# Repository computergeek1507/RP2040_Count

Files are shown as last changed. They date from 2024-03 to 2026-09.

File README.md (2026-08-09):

# Copyright and Disclaimer
Copyright: Scott Hanson

This documentation describes Open Hardware and is licensed under the CERN Open Hardware License Version 2 - Strongly Reciprocal. (CERN-OHL-S)

You may redistribute and modify this documentation under the terms of the CERN OHL-S-v2 (https://ohwr.org/cern_ohl_s_v2.txt). This documentation is distributed WITHOUT ANY EXPRESS OR IMPLIED WARRANTY, INCLUDING OF MERCHANTABILITY, SATISFACTORY QUALITY AND FITNESS FOR A PARTICULAR PURPOSE. Please see the CERN OHL v2-S for applicable conditions

**Under CERN OHL-S-v2, derivative work must be publicly released as defined in subsection 3.3**

# SB Pixel Count




SB Pixel Count is a 'pocket' Pixel Counter. The original (V1) board uses a Waveshare RP2040-Tiny Development Board.  All the design files are open source and available on github.

To order PCBs upload the ["GERBER-SB_Pixel_Count.zip"](https://github.com/computergeek1507/SB_Pixel_Count/raw/main/V1/PCB/jlcpcb/production_files/GERBER-SB_Pixel_Count.zip) file in the "V1\PCB\jlcpcb\production_files" folder to jlcpcb.com. Use the "BOM-SB_Pixel_Count.csv" for the JLC Assembly BOM and "CPL-SB_Pixel_Count.csv" as the footprint placement file.

## Assembly

The raw PCB's from JLC will be missing the RP2040-Tiny, OLED, Push Button and PigTails. These parts need to be soldered manually. The case is designed for flat pigtails.

Print the case out of PETG with 0.1mm layer height. Use #2-56 3/8" machine screws for case.

## Board Variants

This repo tracks a few PCB/firmware revisions side by side. `Firmware/SB_Pixel_Count/BoardConfig.h` selects the pin mapping for each via a build flag (`VERSION1`/`VERSION2`/`VERSION3`); the default is `VERSION2`.

| Variant | Folder | MCU module | Firmware | Interactive BOM | Notes |
| --- | --- | --- | --- | --- | --- |
| V1 (Original) | [`V1/`](https://github.com/computergeek1507/SB_Pixel_Count/tree/main/V1) | Waveshare RP2040-Tiny | `VERSION1` | [Open](https://computergeek1507.github.io/SB_Pixel_Count/V1/PCB/bom/ibom.html) | The board described above. |
| V2 | [`V2/`](https://github.com/computergeek1507/SB_Pixel_Count/tree/main/V2) | Seeed XIAO RP2040 | `VERSION2` (default) | [Open](https://computergeek1507.github.io/SB_Pixel_Count/V2/PCB/bom/ibom.html) | Standard redesign around the XIAO RP2040 module - firmware updates over USB (drag-and-drop UF2), no external programmer needed. |
| V2 Lite | [`V2 Lite/`](https://github.com/computergeek1507/SB_Pixel_Count/tree/main/V2%20Lite) | ATtiny1614 (megaTinyCore) | [`Firmware/ATtiny1614_Count/`](https://github.com/computergeek1507/SB_Pixel_Count/tree/main/Firmware/ATtiny1614_Count) | [Open](https://computergeek1507.github.io/SB_Pixel_Count/V2%20Lite/PCB/bom/ibom.html) | Cost-reduced BOM built around a bare ATtiny1614 instead of a RP2040 module; trades USB firmware updates for a UPDI programmer requirement. Uses FAB_LED/SSD1306Ascii instead of the Adafruit libraries to fit in 16KB flash / 2KB RAM. Shares the same case as V2 (`V2/Case/` and `V2 Lite/Case/` are the same design). |
| V3 Pro | [`V3 Pro/`](https://github.com/computergeek1507/SB_Pixel_Count/tree/main/V3%20Pro) | Seeed XIAO RP2040 | `VERSION3` | [Open](https://computergeek1507.github.io/SB_Pixel_Count/V3%20Pro/PCB/bom/ibom.html) | Adds a second button and a microSD card slot for playing back xLights FSEQ sequences on the strip (`Firmware/SB_Pixel_Count/FseqPlayer.*`). |

Each variant folder that has its own `PCB/` directory also has its own `jlcpcb/production_files` gerbers/BOM/CPL for ordering that specific board.

## [Video of SB Pixel Count](https://youtu.be/7ThN9TBFA-g)

## [Part BOM](https://github.com/computergeek1507/SB_Pixel_Count/raw/main/V1/PCB/SB_Pixel_Count_BOM.ods)

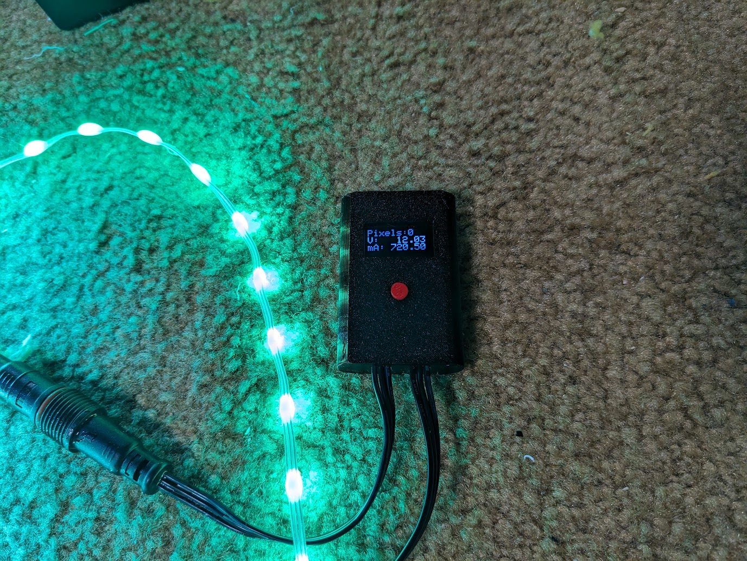
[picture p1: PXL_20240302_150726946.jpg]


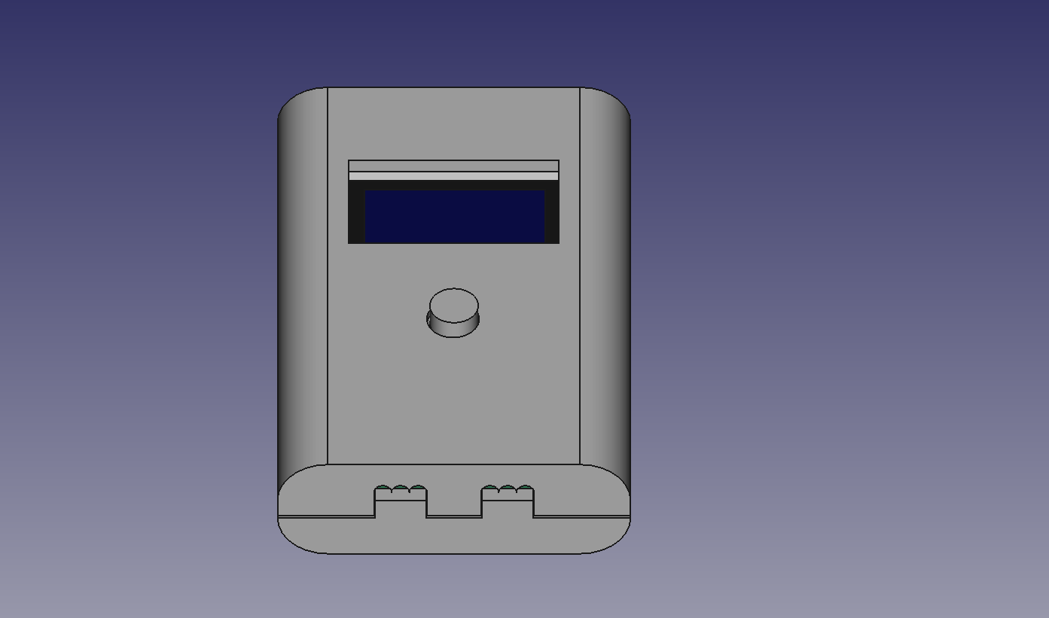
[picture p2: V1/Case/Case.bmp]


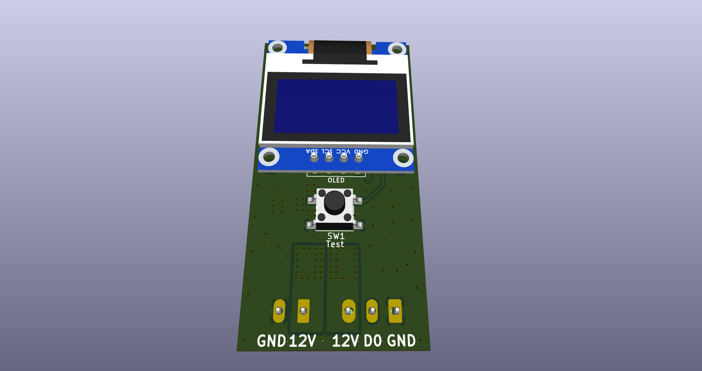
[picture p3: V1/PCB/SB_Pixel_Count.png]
Image of SB Pixel Count


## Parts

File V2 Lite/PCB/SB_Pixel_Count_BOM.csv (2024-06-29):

Reference | Value | Datasheet | Qty | Digi-Key_PN | MPN
C1,C5,C6 | 0.1uF | ~ | 3 | 1276-1005-1-ND | CL10B104KO8NNNC
C3,C4 | 10uF | ~ | 2 | 490-5523-1-ND | GRM21BR61E106KA73L
J2 | String1 | ~ | 1 | 277-5737-ND/ED10555-ND | 1843619/OSTTJ0311530
J3 | OLED | https://www.amazon.com/dp/B06XRBTBTB/ref=sspa_dk_detail_0 | 1
R1 | 33ohm | ~ | 1 | 311-33GRCT-ND | RC0603JR-0733RL
R2 | 0.1 OHM 2W | ~ | 1 | CSRN2512FTR100CT-ND | CSRN2512FTR100
R3,R4 | 10K | ~ | 2 | 311-10.0KHRCT-ND | RC0603FR-0710KL
SW1 | Test | ~ | 1 | CKN10880CT-ND | PTS645SL43SMTR92 LFS
TB1 | Power In |  | 1 | A98472-ND | 4DB-P108-02
U1 | 74AHCT1G125 | http://www.ti.com/lit/sg/scyt129e/scyt129e.pdf | 1 | 74AHCT1G125W5-7DICT-ND | 74AHCT1G125W5-7
U2 | MOUDLE-SEEEDUINO-XIAO |  | 1 | 1597-102010428-ND | 102010428
U3 | AMS1117-5.0 | http://www.advanced-monolithic.com/pdf/ds1117.pdf | 1 | 488-LM1117MPX-50NOPBCT-ND | LM1117MPX-50NOPB
U4 | INA219BxD | http://www.ti.com/lit/ds/symlink/ina219.pdf | 1 | 296-27899-1-ND | INA219BIDR

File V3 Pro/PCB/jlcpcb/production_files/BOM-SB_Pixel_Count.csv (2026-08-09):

Comment | Designator | Footprint | LCSC | Quantity
0.1 OHM 2W | R2 | R_2512_6332Metric_Pad1.40x3.35mm_HandSolder | C2903476 | 1
0.1uF | C1,C5,C6 | C_0603_1608Metric_Pad1.08x0.95mm_HandSolder | C14663 | 3
10K | R3,R4 | R_0603_1608Metric_Pad0.98x0.95mm_HandSolder | C25804 | 2
10uF | C3,C4 | C_0805_2012Metric_Pad1.18x1.45mm_HandSolder | C15850 | 2
33ohm | R1 | R_0603_1608Metric_Pad0.98x0.95mm_HandSolder | C23140 | 1
74AHCT1G125 | U1 | TSOP-5_1.65x3.05mm_P0.95mm | C7484 | 1
AMS1117-5.0 | U3 | SOT-223-3_TabPin2 | C6187 | 1
INA219BxD | U4 | SOIC-8_3.9x4.9mm_P1.27mm | C138706 | 1
Menu | SW2 | SW_PUSH_6mm | C2834918 | 1
TF-123-ARP9H17 | U5 | TF-SMD_TF-123-ARP9H15 | C2982548 | 1
Test | SW1 | SW_PUSH_6mm | C2834918 | 1

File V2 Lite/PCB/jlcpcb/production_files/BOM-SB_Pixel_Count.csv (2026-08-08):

Comment | Designator | Footprint | LCSC | Quantity
0.1 OHM 2W | R2 | R_2512_6332Metric_Pad1.40x3.35mm_HandSolder | C2903476 | 1
0.1uF | C1,C5,C6 | C_0603_1608Metric_Pad1.08x0.95mm_HandSolder | C14663 | 3
10K | R3,R4 | R_0603_1608Metric_Pad0.98x0.95mm_HandSolder | C25804 | 2
10uF | C2,C3,C4 | C_0805_2012Metric_Pad1.18x1.45mm_HandSolder | C15850 | 3
330 | R5 | R_0603_1608Metric_Pad0.98x0.95mm_HandSolder | C23138 | 1
33ohm | R1 | R_0603_1608Metric_Pad0.98x0.95mm_HandSolder | C23140 | 1
3v3 | D1 | LED_0603_1608Metric | C2286 | 1
74AHCT1G125 | U1 | TSOP-5_1.65x3.05mm_P0.95mm | C7484 | 1
AMS1117-5.0 | U3 | SOT-223-3_TabPin2 | C6187 | 1
AP2112K-3.3 | U2 | SOT-23-5 | C51118 | 1
ATtiny1614-SS | U6 | SOIC-14_3.9x8.7mm_P1.27mm | C481364 | 1
INA219BxD | U4 | SOIC-8_3.9x4.9mm_P1.27mm | C138706 | 1
Test | SW1 | SW_PUSH_6mm | C2834918 | 1

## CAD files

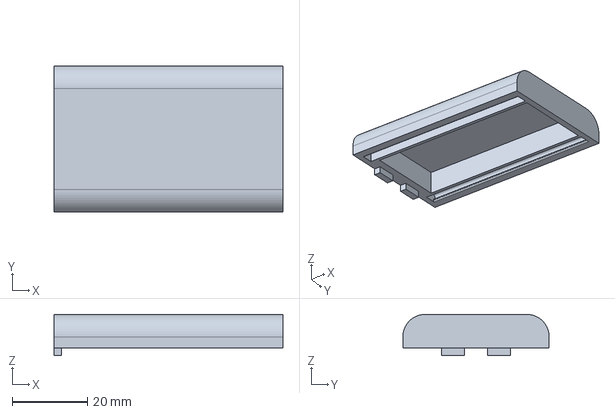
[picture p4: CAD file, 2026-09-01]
V2/Case/sb_pixel_count_caseV2_Snap.FCStd
61.0 x 39.0 x 11.0 mm

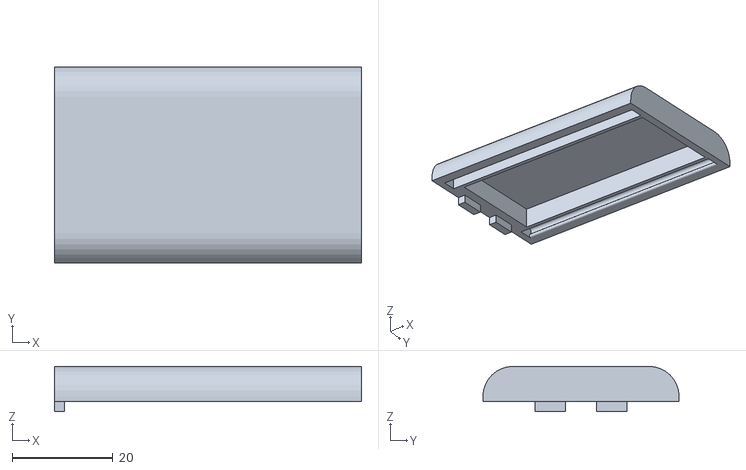
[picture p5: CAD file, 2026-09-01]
V2/Case/sb_pixel_count_caseV2_Snap-back_case.stl
61.0 x 39.0 x 9.00

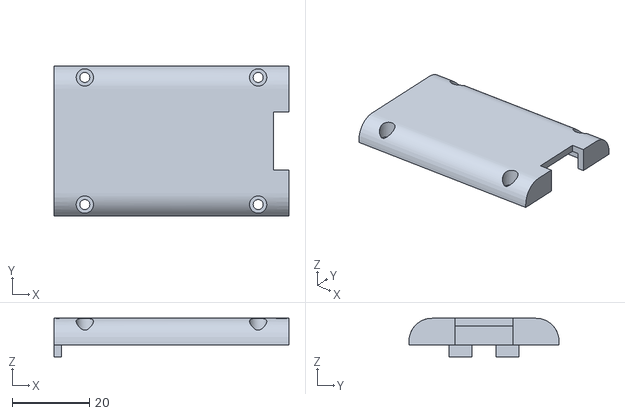
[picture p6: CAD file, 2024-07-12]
V2/Case/sb_pixel_count_caseV2-back_case_debug.stl
61.0 x 39.0 x 10.0

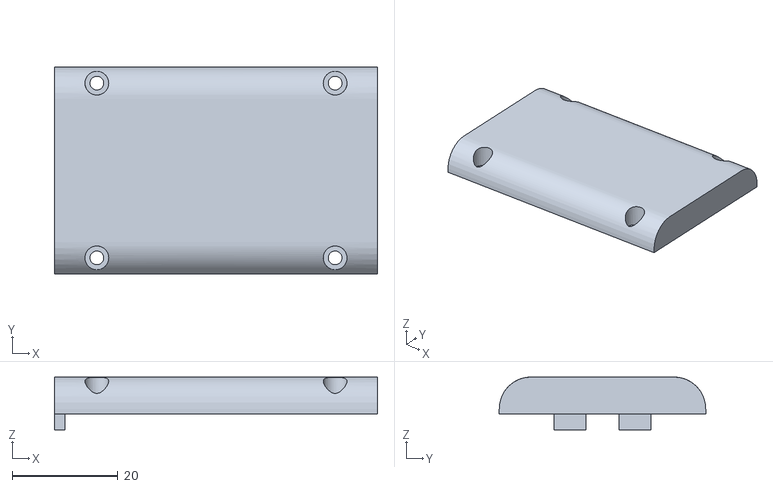
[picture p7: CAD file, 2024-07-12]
V2/Case/sb_pixel_count_caseV2-back_case.stl
61.0 x 39.0 x 10.0

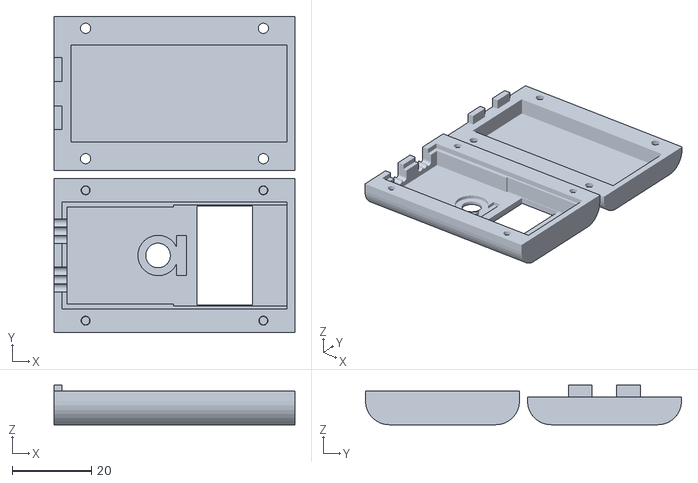
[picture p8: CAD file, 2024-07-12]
V2/Case/sb_pixel_count_caseV2-case.stl
61.0 x 80.0 x 10.0

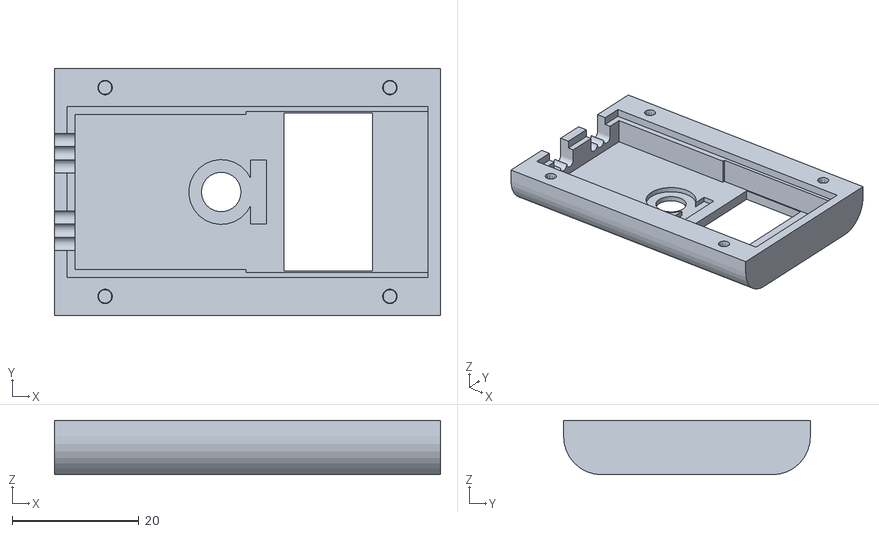
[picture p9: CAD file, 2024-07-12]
V2/Case/sb_pixel_count_caseV2-front_case.stl
61.0 x 39.0 x 8.60

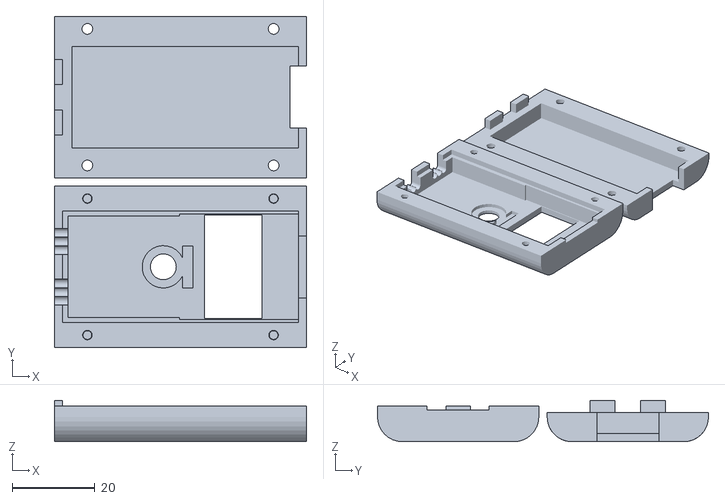
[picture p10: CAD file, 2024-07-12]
V2/Case/sb_pixel_count_caseV2-case_debug.stl
61.0 x 80.0 x 10.0

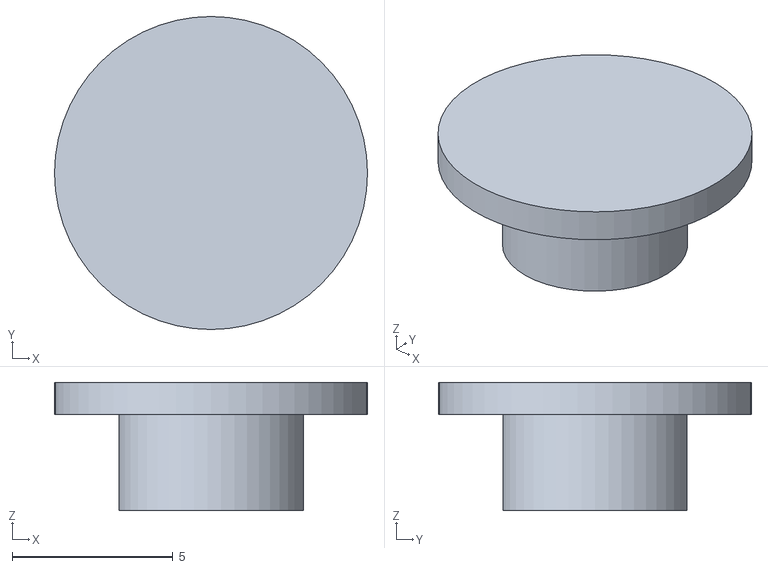
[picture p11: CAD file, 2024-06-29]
V2/Case/sb_pixel_count_caseV2-button.stl
9.75 x 9.75 x 4.00

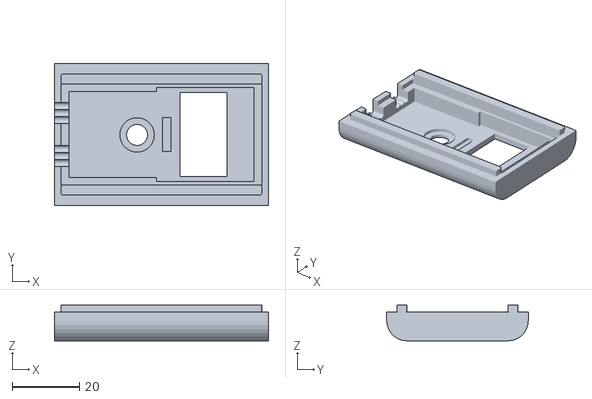
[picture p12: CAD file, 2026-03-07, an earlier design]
V1/Case/sb_pixel_count_case_snap-front_case.stl
63.5 x 42.0 x 10.6

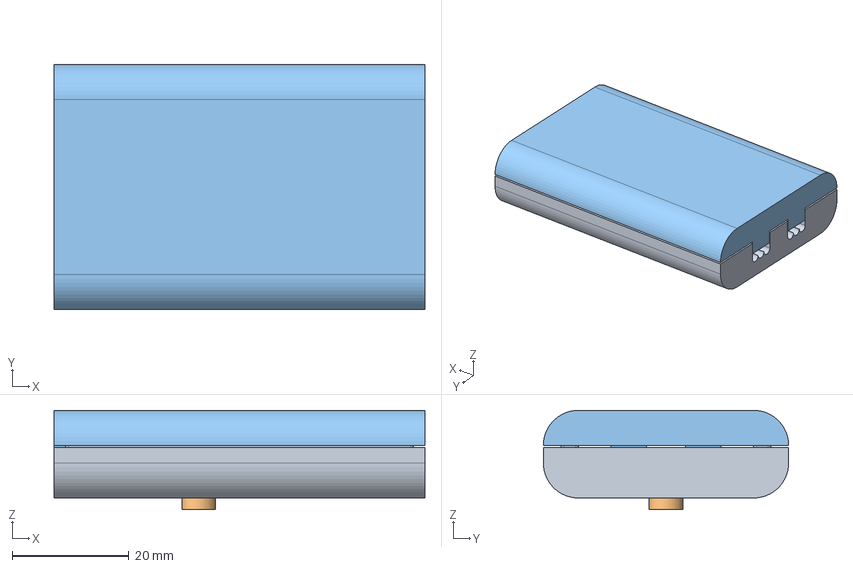
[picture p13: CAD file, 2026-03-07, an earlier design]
V1/Case/sb_pixel_count_case_snap.FCStd
63.5 x 42.0 x 17.0 mm
front_case
button
back_case

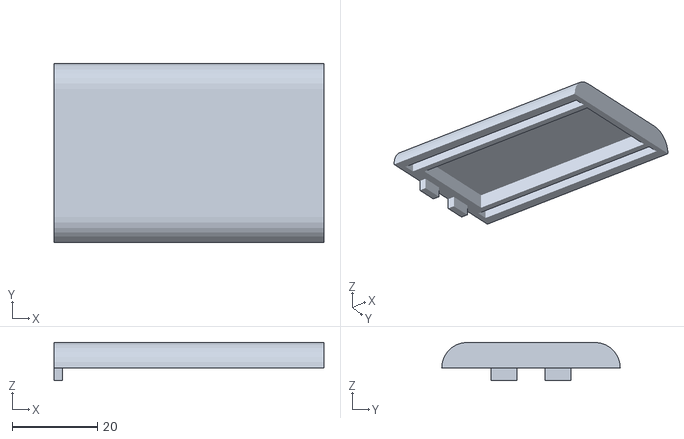
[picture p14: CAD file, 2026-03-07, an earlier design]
V1/Case/sb_pixel_count_case_snap-back_case.stl
63.5 x 42.0 x 9.00

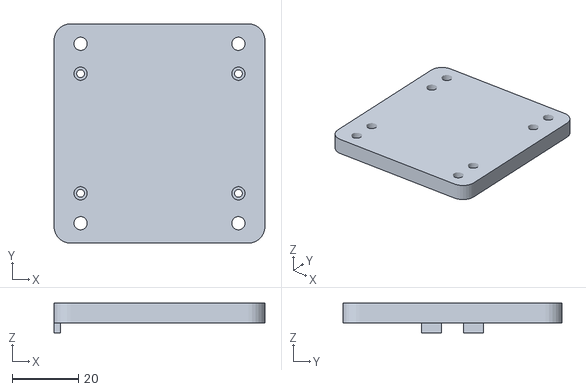
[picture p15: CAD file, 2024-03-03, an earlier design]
V1/Case/sb_pixel_count_case-back_case_wall.stl
63.5 x 66.0 x 9.00

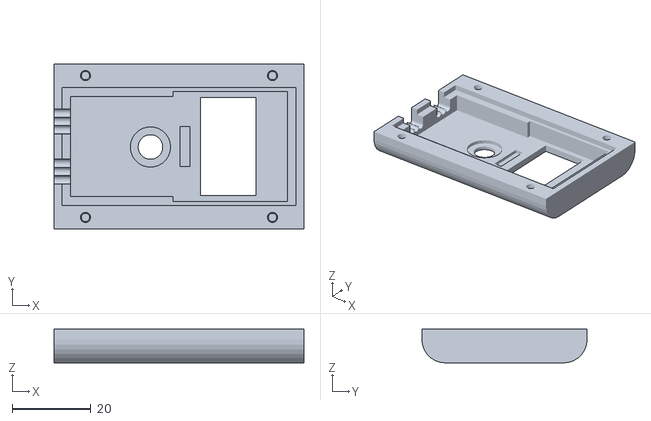
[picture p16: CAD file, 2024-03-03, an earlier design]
V1/Case/sb_pixel_count_case-front_case.stl
63.5 x 42.0 x 8.60

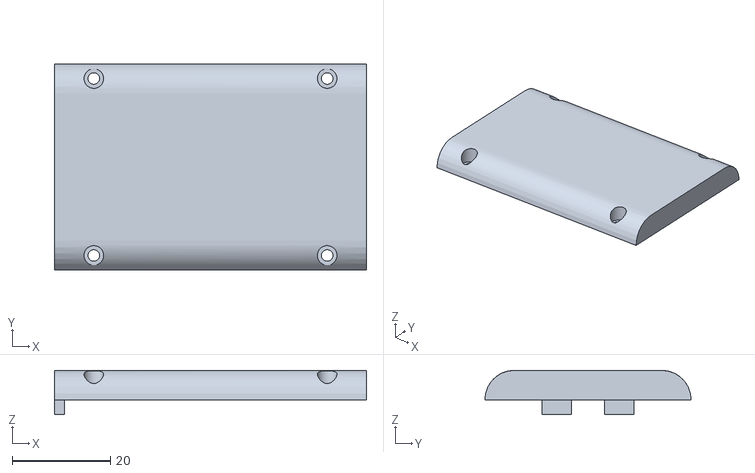
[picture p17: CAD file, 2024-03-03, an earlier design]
V1/Case/sb_pixel_count_case-back_case.stl
63.5 x 42.0 x 9.00

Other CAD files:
V2/Case/sb_pixel_count_caseV2.FCStd
V1/Case/sb_pixel_count_case-Button.stl
V1/Case/sb_pixel_count_case.FCStd

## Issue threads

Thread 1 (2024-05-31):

Programming RP2040

brymitch56, 2024-05-31:
Probably just my ignorance of the RP2040, but what is the recommended method for programming the board for this application? I see the .ino file, but I'm getting errors using the Arduino IDE. The compiler is saying it found multiple libraries for all of the included libraries, although I've confirmed only one instance of each library is installed.

computergeek1507, 2024-05-31:
I also included the uf2 files as well, if you plugged in the rp2040 it should mount as a USB drive and you drag and drop the uf2 file into the USB drive.

brymitch56, 2024-05-31:
I saw that file, but didn't know what it was. Thanks. I'll give that a try. Might be helpful to put that information in the readme for others who may not be as familiar with the RP2040 like me.

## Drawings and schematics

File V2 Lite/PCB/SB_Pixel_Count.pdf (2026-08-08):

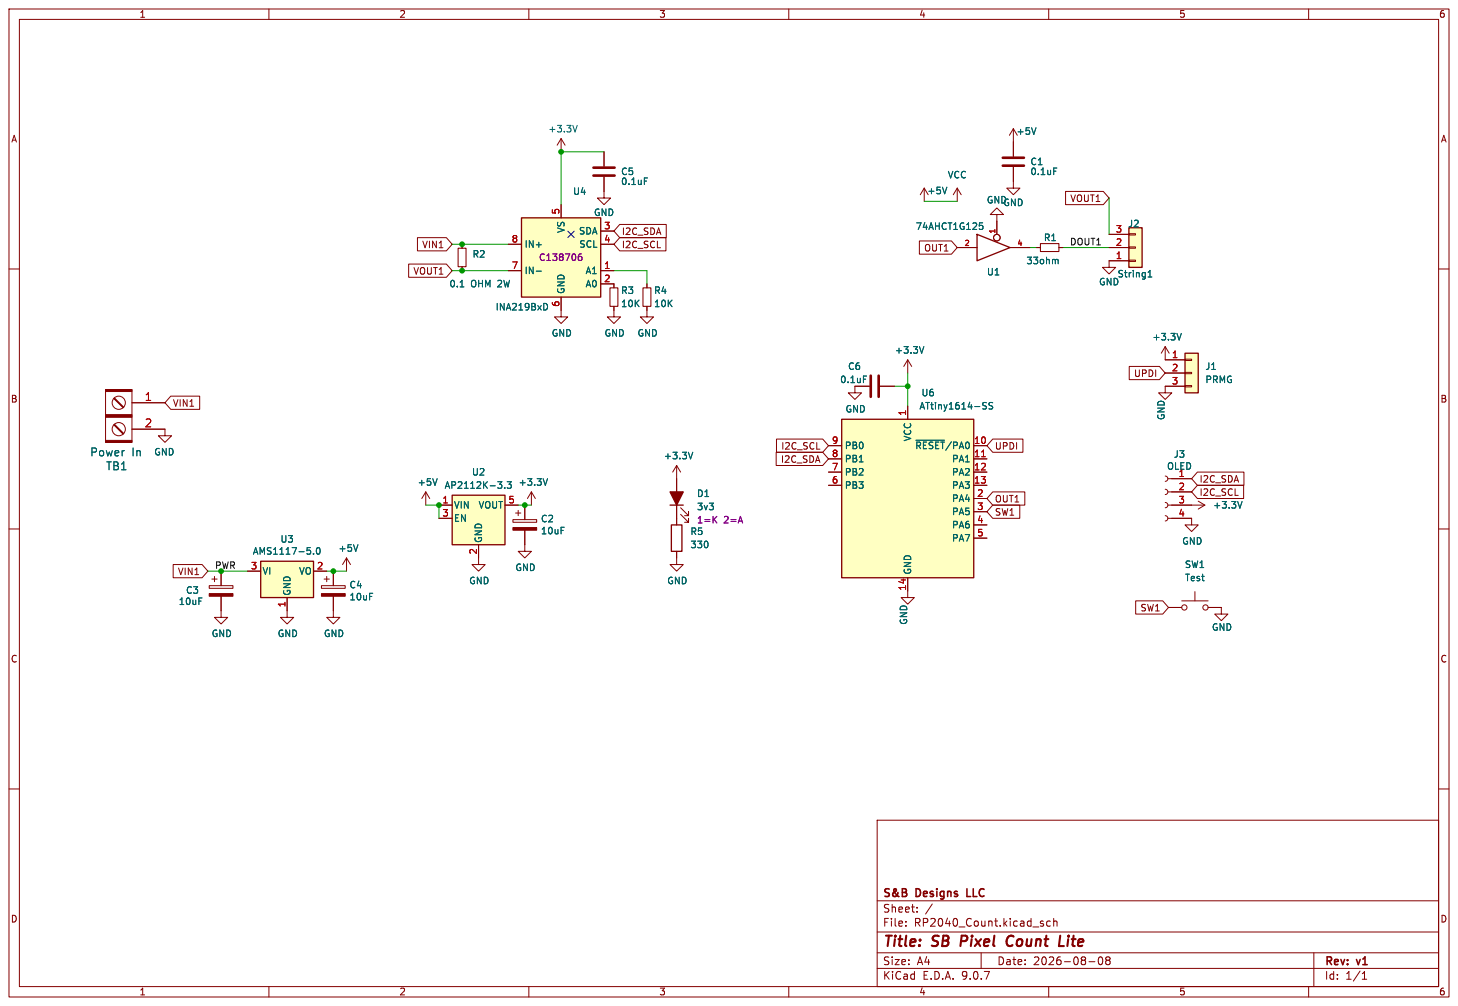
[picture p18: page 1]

Id: 1/1 Title: SB Pixel Count Lite

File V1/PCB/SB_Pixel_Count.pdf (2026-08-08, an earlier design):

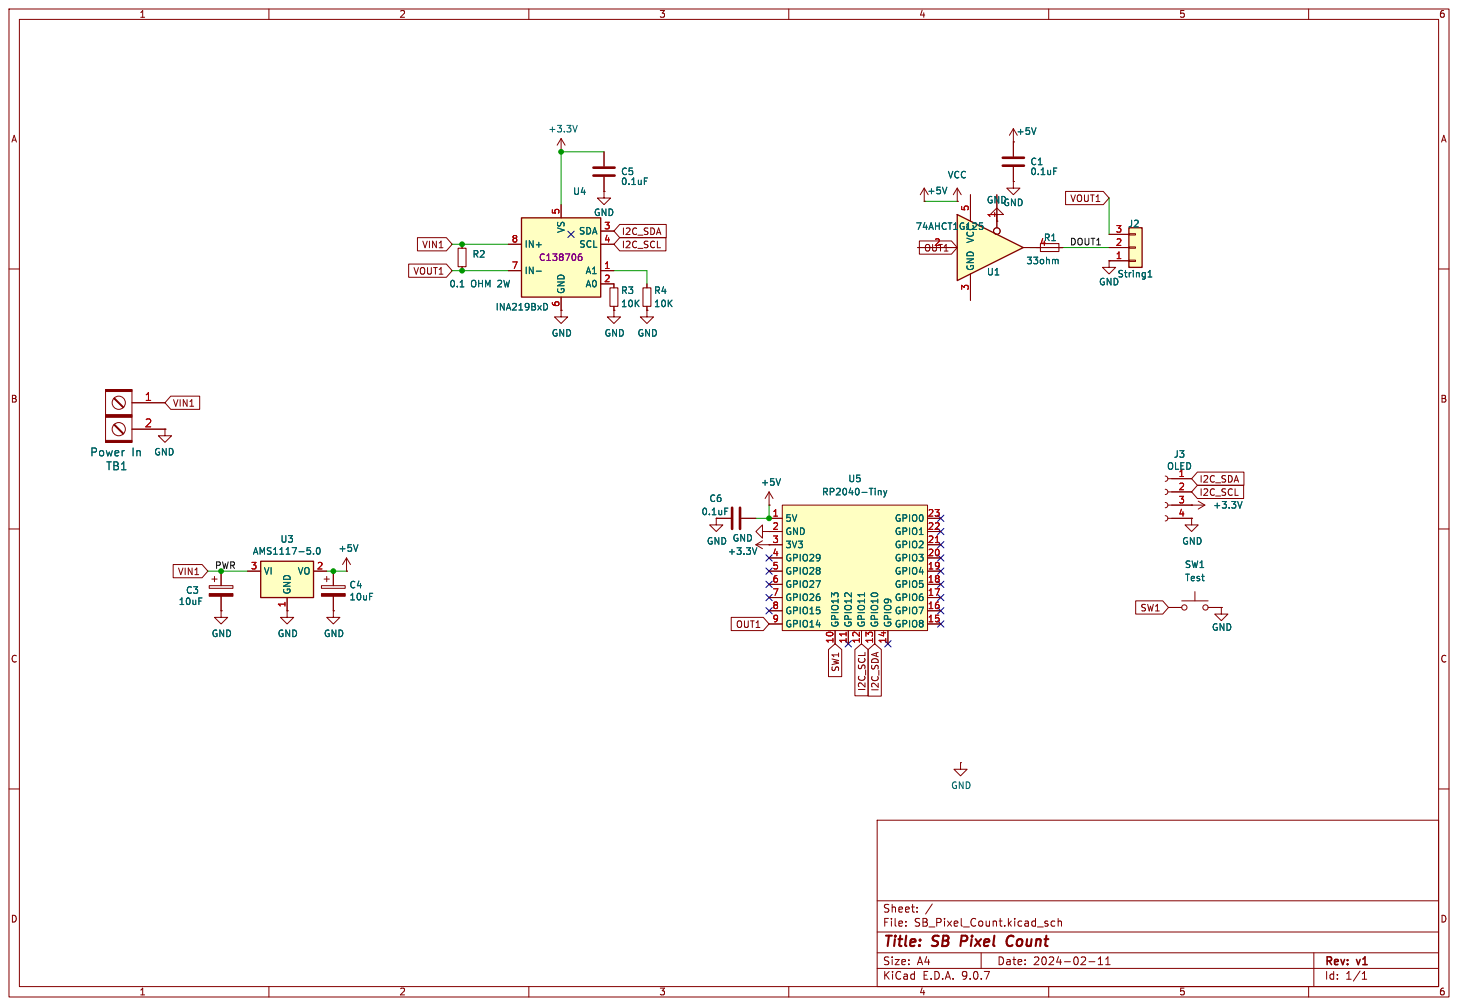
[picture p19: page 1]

6 SDA 3 SCL 4 A1 1 A0 2 GND GND GND

Id: 1/1 Title: SB Pixel Count File: SB_Pixel_Count.kicad_sch Sheet: /

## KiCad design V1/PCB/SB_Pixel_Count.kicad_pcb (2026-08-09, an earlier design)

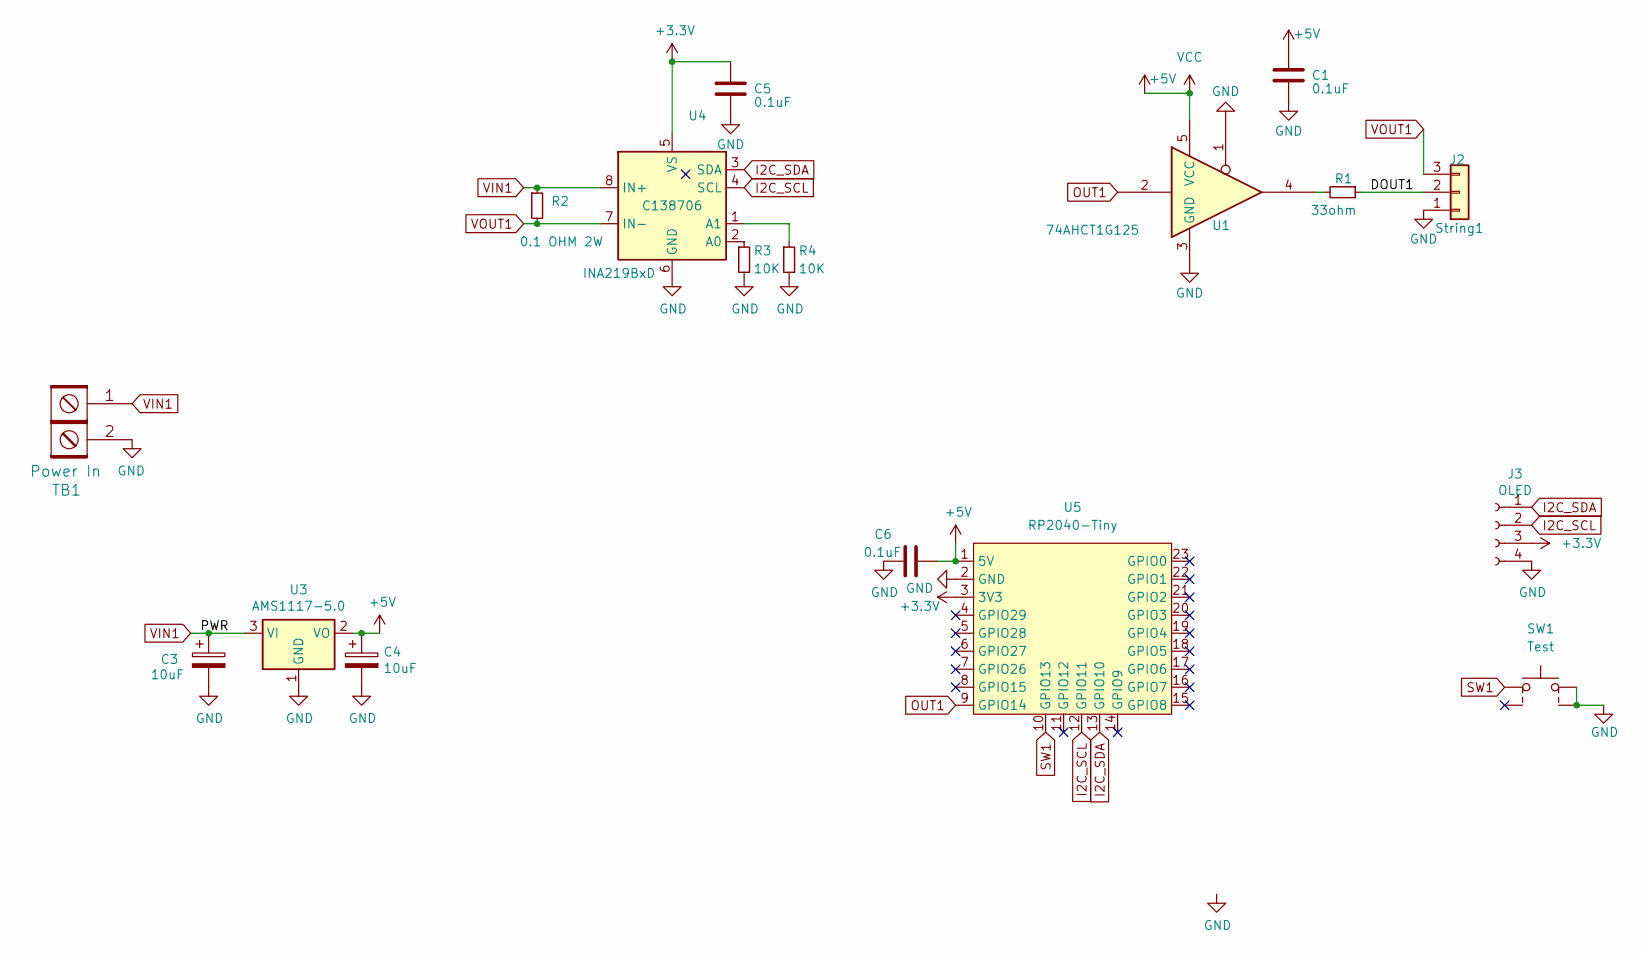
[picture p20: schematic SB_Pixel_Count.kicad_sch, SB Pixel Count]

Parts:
C1, C5: 0.1uF; C_0603_1608Metric_Pad1.08x0.95mm_HandSolder; MPN CL10B104KO8NNNC; LCSC C14663
C3, C4: 10uF; C_0805_2012Metric_Pad1.18x1.45mm_HandSolder; MPN GRM21BR61E106KA73L; Digi-Key_PN 490-5523-1-ND
C6: 0.1uF; C_0603_1608Metric_Pad1.08x0.95mm_HandSolder; MPN CL10B104KO8NNNC; Digi-Key_PN 1276-1005-1-ND
J2: String1; PhoenixContact_MCV_3.81mm_3.5mm_1x03_Vertical; MPN 1843619/OSTTJ0311530; Digi-Key_PN 277-5737-ND/ED10555-ND
J3: OLED; OLED-SSD1306-128X64-I2C-THT_SCOTT2; LCSC C225501
R1: 33ohm; R_0603_1608Metric_Pad0.98x0.95mm_HandSolder; MPN RC0603JR-0733RL; LCSC_PN C23140
R2: 0.1 OHM 2W; R_2512_6332Metric_Pad1.40x3.35mm_HandSolder; MPN CSRN2512FTR100; Digi-Key_PN CSRN2512FTR100CT-ND
R3, R4: 10K; R_0603_1608Metric_Pad0.98x0.95mm_HandSolder; MPN RC0603FR-0710KL; Digi-Key_PN 311-10.0KHRCT-ND
SW1: Test; SW_Push_1P1T_NO_6x6mm_H9.5mm; MPN PTS645SL43SMTR92 LFS; LCSC C2834918
TB1: Power In; PhoenixContact_MCV_1,5_2-G-3.81_1x02_P3.81mm_Vertical; MPN 4DB-P108-02; Digi-Key_PN A98472-ND
U1: 74AHCT1G125; TSOP-5_1.65x3.05mm_P0.95mm; MPN 74AHCT1G125W5-7; Digi-Key_PN 74AHCT1G125W5-7DICT-ND
U3: AMS1117-5.0; SOT-223-3_TabPin2; MPN LM1117MPX-50NOPB; LCSC_PN C6187
U4: INA219BxD; SOIC-8_3.9x4.9mm_P1.27mm; MPN INA219BIDR; LCSC C138706
U5: RP2040-Tiny; RP2040-Tiny_Scott

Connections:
+3.3V: C5.1, J3.3, U4.5 (VS), U5.3 (3V3)
+5V: C1.1, C4.1, C6.2, U1.5 (VCC), U3.2 (VO), U5.1 (5V)
/DOUT1: J2.2, R1.1
GND: C1.2, C3.2, C4.2, C5.2, C6.1, J2.1, J3.4, R3.2, R4.2, SW1.2, SW1.4, TB1.2, U1.1, U1.3 (GND), U3.1 (GND), U4.6 (GND), U5.2 (GND)
I2C_SCL: J3.2, U4.4 (SCL), U5.12 (GPIO11)
I2C_SDA: J3.1, U4.3 (SDA), U5.13 (GPIO10)
unnamed: R1.2, U1.4
unnamed: R3.1, U4.2 (A0)
unnamed: R4.1, U4.1 (A1)
OUT1: U1.2, U5.9 (GPIO14)
SW1: SW1.1, U5.10 (GPIO13)
VIN1: C3.1, R2.1, TB1.1, U3.3 (VI), U4.8 (IN+)
VOUT1: J2.3, R2.2, U4.7 (IN-)

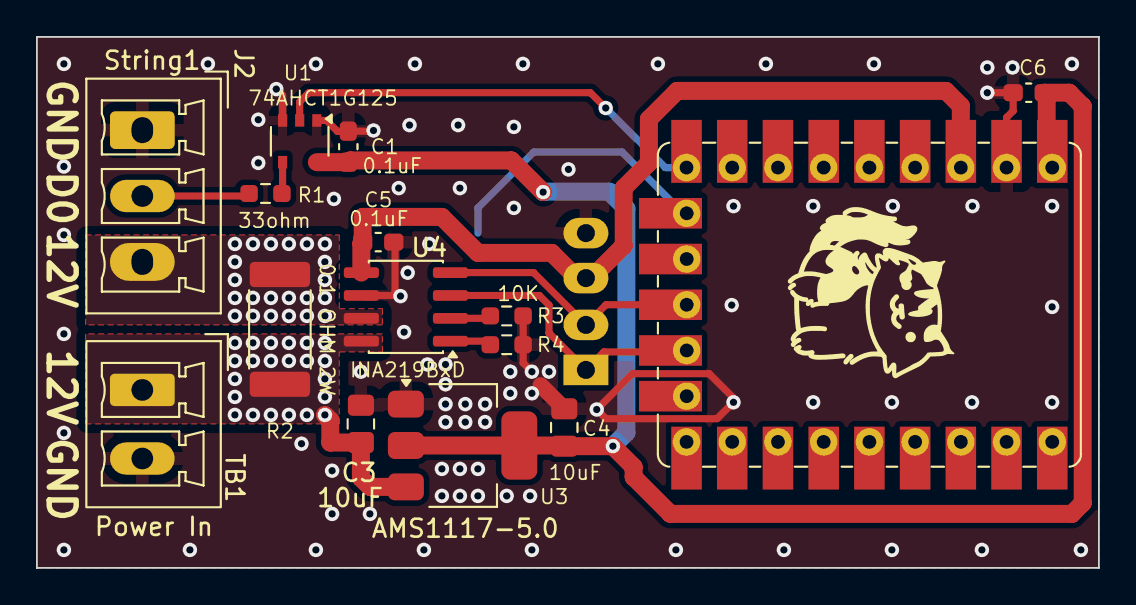
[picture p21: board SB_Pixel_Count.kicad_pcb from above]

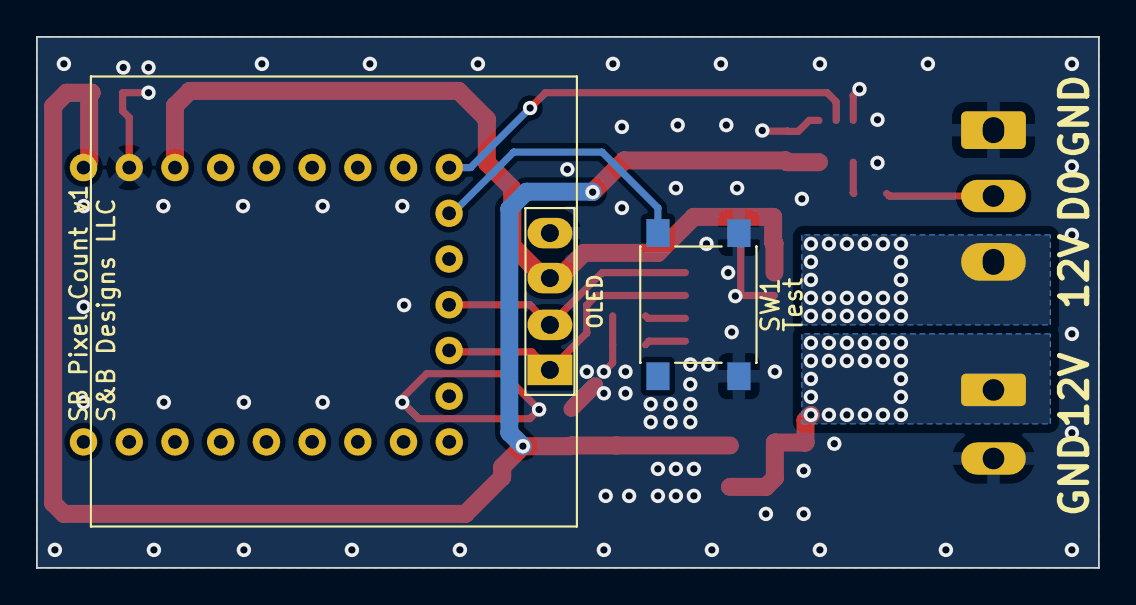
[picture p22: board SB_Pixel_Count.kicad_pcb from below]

Board: 2 copper layers, 59.0 x 29.5 mm, 17 parts (2 on the bottom side), 13 nets.

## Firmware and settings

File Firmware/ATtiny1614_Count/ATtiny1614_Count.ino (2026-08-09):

// ATtiny1614 port of SB_Pixel_Count.
//
// Board (Boards Manager): megaTinyCore "ATtiny3224/1624/1614/1604/824/814/804/
// 424/414/404/214/204", chip=1614, no bootloader (UPDI programmer required).
// Flash/RAM budget is tight (16KB / 2KB) so this port avoids Adafruit_GFX,
// Adafruit_SSD1306, Adafruit_NeoPixel and Adafruit_INA219: those libraries
// assume a buffered strip/framebuffer and pull in float-format/BusIO code
// that doesn't fit. Swapped for FAB_LED (streams pixels with no strip
// buffer), SSD1306Ascii (text-only, no framebuffer), and a minimal
// register-level INA219 reader.
//
// Wiring (ATtiny1614, 14-pin):
//   PA4 (digital 0) -> NeoPixel data in
//   PA5 (digital 1) -> Button (active low, internal pullup)
//   PB1 (digital 6) -> SDA (hardware TWI0, default pins)
//   PB0 (digital 7) -> SCL (hardware TWI0, default pins)
//   PA0 (UPDI)      -> reserved for programming, not used as GPIO
// INA219 shunt is 0.1 ohm (matches SB_Pixel_Count.kicad_sch, R "0.1 OHM 2W").
//
// Power/level-shifting (for whoever lays out the PCB): the SSD1306 needs a
// 3V supply, and I2C is open-drain, so ATtiny1614 + INA219 + OLED should all
// share a 3.3V rail rather than 5V (both chips are fine at 3.3V). That
// leaves the NeoPixel data line under-driven: WS2812B wants a data-high
// threshold near 0.7*Vdd (~3.5V on a 5V-powered strip), which a 3.3V GPIO
// won't reliably hit over a run this long (801 pixels). SB_Pixel_Count.kicad_sch
// already solves this on the RP2040 board (same 3.3V-logic situation) with a
// 74AHCT1G125 level shifter on the pixel line - reuse that pattern here:
// 3.3V for MCU/I2C/OLED, level-shift just the PA4 pixel output up to 5V.

#include <Wire.h>
#include <FAB_LED.h>
#include <SSD1306Ascii.h>
#include <SSD1306AsciiWire.h>
#include <OneButton.h>

#define BUTTON_A_PIN  1  // PA5

#define PIXEL_COUNT 801  // Number of NeoPixels
#define PIXEL_CURRENT_DIFF1 10
#define PIXEL_CURRENT_DIFF2 5
#define PIXEL_CURRENT_DIFF3 3
#define CURRENT_READ_DELAY 10
#define CURRENT_REREAD_DELAY 3

#define NUM_OFF_READING 5
#define NUM_SINGLE_READING 3

#define SCREEN_ADDRESS 0x3C  // Address 0x3C default

#define INA219_ADDRESS 0x40
#define INA219_REG_SHUNTVOLTAGE 0x01
#define INA219_REG_BUSVOLTAGE   0x02
#define INA219_SHUNT_OHMS 0.1f  // matches R "0.1 OHM 2W" on SB_Pixel_Count PCB

// ws2812b<A,4> hardcodes GRB wire order internally (see FAB_TVAR_WS2812B in
// FAB_LED.h) - the local pixel struct's field order (rgb vs grb) has no
// effect on it, since sendPixels() always reads .r/.g/.b by name and
// reorders per this class's fixed `colors` template param. This strip
// actually wants RGB order, so instantiate the base template directly
// with RGB in place of ws2812b's hardcoded GRB (everything else is an
// exact copy of what ws2812b<A,4> expands to).
avrBitbangLedStrip<WS2812B_1H_CY, WS2812B_1L_CY, WS2812B_0H_CY, WS2812B_0L_CY,
                    WS2812B_MS_REFRESH, A, 4, A, 0, RGB, ONE_PORT_BITBANG> strip;  // NeoPixel data on PA4
SSD1306AsciiWire oled;

OneButton button = OneButton(
  BUTTON_A_PIN,  // Input pin for the button
  true,          // Button is active LOW
  true           // Enable internal pull-up resistor
);

uint32_t pixel_count = 0;
uint16_t color = 0;
volatile int mode = 0;

// ---- Minimal INA219 register access (no calibration register, no BusIO) ----
// Relies on the INA219's power-on-reset default config (continuous
// shunt+bus conversion, 12-bit ADC, +-320mV shunt range), so no config
// write is needed at startup.

int16_t ina219_read16(uint8_t reg) {
  Wire.beginTransmission(INA219_ADDRESS);
  Wire.write(reg);
  Wire.endTransmission();
  Wire.requestFrom(INA219_ADDRESS, (uint8_t)2);
  uint16_t value = (uint16_t)Wire.read() << 8;
  value |= Wire.read();
  return (int16_t)value;
}

float ina219_getShuntVoltage_mV() {
  return ina219_read16(INA219_REG_SHUNTVOLTAGE) * 0.01f;  // LSB = 10uV
}

float ina219_getBusVoltage_V() {
  uint16_t raw = (uint16_t)ina219_read16(INA219_REG_BUSVOLTAGE);
  return (raw >> 3) * 0.004f;  // top 13 bits, LSB = 4mV
}

float ina219_getCurrent_mA() {
  return ina219_getShuntVoltage_mV() / INA219_SHUNT_OHMS;
}

// ---- Streaming NeoPixel helpers (FAB_LED holds no strip buffer) ----

void setAllColor(uint8_t r, uint8_t g, uint8_t b) {
  rgb pix[1];
  pix[0].r = r;
  pix[0].g = g;
  pix[0].b = b;
  const uint8_t oldSREG = SREG;
  cli();
  for (uint16_t i = 0; i < PIXEL_COUNT; i++) {
    strip.sendPixels(1, pix);
  }
  SREG = oldSREG;
}

void turnOnLED(uint16_t ledidx) {
  rgb pix[1];
  const uint8_t oldSREG = SREG;
  cli();
  for (uint16_t i = 0; i < PIXEL_COUNT; i++) {
    if (i == ledidx) {
      pix[0].r = 255; pix[0].g = 255; pix[0].b = 255;
    } else {
      pix[0].r = 0; pix[0].g = 0; pix[0].b = 0;
    }
    strip.sendPixels(1, pix);
  }
  SREG = oldSREG;
  delay(CURRENT_READ_DELAY);
}

// Input 0-255, returns a packed 0x00RRGGBB color transitioning r-g-b-r.
uint32_t wheel(uint8_t wheelPos) {
  wheelPos = 255 - wheelPos;
  if (wheelPos < 85) {
    return ((uint32_t)(255 - wheelPos * 3) << 16) | (uint32_t)(wheelPos * 3);
  }
  if (wheelPos < 170) {
    wheelPos -= 85;
    return ((uint32_t)(wheelPos * 3) << 8) | (uint32_t)(255 - wheelPos * 3);
  }
  wheelPos -= 170;
  return ((uint32_t)(255 - wheelPos * 3) << 8) | (uint32_t)(wheelPos * 3);
}

void rainbowCycle(uint16_t colorOffset) {
  rgb pix[1];
  const uint8_t oldSREG = SREG;
  cli();
  for (uint16_t i = 0; i < PIXEL_COUNT; i++) {
    uint32_t c = wheel((uint8_t)(((uint32_t)i * 256 / PIXEL_COUNT + colorOffset) & 255));
    pix[0].r = (c >> 16) & 0xFF;
    pix[0].g = (c >> 8) & 0xFF;
    pix[0].b = c & 0xFF;
    strip.sendPixels(1, pix);
  }
  SREG = oldSREG;
}

void setColorWith50() {
  rgb pix[1];
  const uint8_t oldSREG = SREG;
  cli();
  for (uint16_t i = 0; i < PIXEL_COUNT; i++) {
    bool marker = ((i + 1) % 50 == 0) && (i != 0);
    pix[0].r = 255;
    pix[0].g = marker ? 255 : 0;
    pix[0].b = marker ? 255 : 0;
    strip.sendPixels(1, pix);
  }
  SREG = oldSREG;
}

// ---- Display ----

void update_power_display(uint16_t pixelNum, const char* mode_str) {
  float shuntvoltage = ina219_getShuntVoltage_mV();
  float busvoltage = ina219_getBusVoltage_V();
  float current_mA = ina219_getCurrent_mA();
  float loadvoltage = busvoltage + (shuntvoltage / 1000.0f);

  // No oled.clear() here: blanking the whole 1024-byte GDDRAM before
  // redrawing text is what caused the visible flicker. Overwrite each
  // field in place and clearToEOL() just the leftover tail instead.
  oled.setCursor(0, 0);
  oled.print("Pixels:");
  oled.print(pixelNum);
  oled.clearToEOL();

  oled.setCursor(0, 2);
  oled.print("V:");
  oled.print(loadvoltage, 2);
  oled.clearToEOL();

  oled.setCursor(0, 4);
  oled.print("A:");
  oled.print(current_mA / 1000.0f, 3);
  oled.clearToEOL();

  oled.setCursor(0, 6);
  oled.print(mode_str);
  oled.clearToEOL();
}

// ---- Pixel counting (binary search on current draw), ported 1:1 ----

bool IsLEDOn(uint16_t ledidx, float off_current, float current_diff) {
  turnOnLED(ledidx);

  float on_current_sum = 0.0f;
  for (int i = 0; i < NUM_SINGLE_READING; i++) {
    on_current_sum += ina219_getCurrent_mA();
    delay(CURRENT_REREAD_DELAY);
  }
  float on_current = on_current_sum / (float)NUM_SINGLE_READING;

  return (on_current - off_current) >= current_diff;
}

int findTransitionPoint(int n, float off_current, float current_diff) {
  int lb = 0;
  int ub = n - 1;

  while (lb <= ub) {
    int mid = (lb + ub) / 2;
    char modeBuf[10];
    snprintf(modeBuf, sizeof(modeBuf), "Cnt %d", (int)current_diff);
    update_power_display(mid, modeBuf);

    if (IsLEDOn(mid, off_current, current_diff)) {
      lb = mid + 1;
    } else {
      if (mid == 0 || (mid > 0 && IsLEDOn(mid - 1, off_current, current_diff))) {
        return mid;
      }
      ub = mid - 1;
    }
  }
  return -1;
}

void countPixels() {
  strip.clear(PIXEL_COUNT);
  delay(50);

  float off_current_sum = 0.0f;
  for (int i = 0; i < NUM_OFF_READING; i++) {
    off_current_sum += ina219_getCurrent_mA();
    delay(CURRENT_REREAD_DELAY);
  }
  float off_current = off_current_sum / (float)NUM_OFF_READING;

  float current_diffs[3] = { PIXEL_CURRENT_DIFF1, PIXEL_CURRENT_DIFF2, PIXEL_CURRENT_DIFF3 };

  for (auto const& cur_diff : current_diffs) {
    int count = findTransitionPoint(PIXEL_COUNT, off_current, cur_diff);
    if (count > 0) {
      pixel_count = count;
      break;
    }
  }
}

// ---- Button callbacks ----

void ShortPress(void* oneButton) {
  if (++mode > 7) {
    mode = 0;
  }
}

void LongPress(void* oneButton) {
  countPixels();
}

// ---- Setup / loop ----

void setup() {
  Wire.begin();
  Wire.setClock(400000L);

  oled.begin(&Adafruit128x64, SCREEN_ADDRESS);
  // Adafruit-style modules power up in remap mode; normal mode rotates
  // the display 180 degrees. Flip back to false if this ends up upside down.
  oled.displayRemap(true);
  oled.setFont(fixed_bold10x15);  // 10x15px bold - bigger/bolder than System5x7.
  // Rows stay at the same 0/2/4/6 cursor positions used below: each text
  // line here is ~15-16px tall (2 of the display's 8px "page" rows), so
  // four lines still fill the 128x64 screen edge-to-edge with no overlap.
  oled.clear();

  strip.clear(PIXEL_COUNT);

  button.attachPress(ShortPress, &button);
  button.attachLongPressStart(LongPress, &button);
  button.setDebounceMs(20);
  button.setLongPressIntervalMs(800);
  delay(100);
  countPixels();
}

void loop() {
  button.tick();

  color++;
  if (color > 255) {
    color = 0;
  }

  const char* mode_str;
  switch (mode) {
    case 0: rainbowCycle(color); mode_str = "Rainbow"; break;
    case 1: setColorWith50(); mode_str = "Every 50"; break;
    case 2: setAllColor(255, 0, 0); mode_str = "Red"; break;
    case 3: setAllColor(0, 255, 0); mode_str = "Green"; break;
    case 4: setAllColor(0, 0, 255); mode_str = "Blue"; break;
    case 5: setAllColor(127, 127, 127); mode_str = "50% White"; break;
    case 6: setAllColor(255, 255, 255); mode_str = "100% White"; break;
    case 7: setAllColor(0, 0, 0); mode_str = "Off"; break;
  }

  delay(10);
  update_power_display(pixel_count, mode_str);
}

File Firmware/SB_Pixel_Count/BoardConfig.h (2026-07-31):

// Pin mapping per PCB revision. VERSION1/VERSION2/VERSION3 is normally set
// via a `-D` build flag (see .github/workflows/compile.yml); uncomment one
// of the #defines below to pick a board when building from the Arduino IDE.
#pragma once

//#define  VERSION1
//#define  VERSION2
//#define  VERSION3
//#define  ON_BOARD_LED

#if !defined(VERSION1) && !defined(VERSION2) && !defined(VERSION3)
#define VERSION2
#endif

#if defined(VERSION1)
#define PIXEL_PIN    14  // Digital IO pin connected to the NeoPixels.
#define BUTTON_A_PIN  13
#define I2C_SDA_PIN  10
#define I2C_SCL_PIN  11
#define WIRE_DEVICE Wire1
#define PIXEL2_PIN    16
#endif

#if defined(VERSION2)
#define PIXEL_PIN    D6  // Digital IO pin connected to the NeoPixels.
#define BUTTON_A_PIN  D7
#define I2C_SDA_PIN  PIN_WIRE0_SDA
#define I2C_SCL_PIN  PIN_WIRE0_SCL
#define WIRE_DEVICE Wire
#define PIXEL2_PIN    12
#endif

#if defined(VERSION3)
// Pro board: adds a second button (SD/FSEQ menu) and a microSD card
// (SPI0: CS=D7, SCK=D8, MISO=D9, MOSI=D10 - default XIAO RP2040 SPI pins).
#define PIXEL_PIN    D6  // Digital IO pin connected to the NeoPixels.
#define BUTTON_A_PIN  D2
#define BUTTON_B_PIN  D3
#define I2C_SDA_PIN  PIN_WIRE0_SDA
#define I2C_SCL_PIN  PIN_WIRE0_SCL
#define WIRE_DEVICE Wire
#define PIXEL2_PIN    12
#define SD_CS_PIN    D7
#define HAS_SD_CARD
#endif

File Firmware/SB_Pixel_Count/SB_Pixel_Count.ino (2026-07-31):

#include <Wire.h>
#include <Adafruit_GFX.h>
#include <Adafruit_SSD1306.h>
#include <Adafruit_INA219.h>
#include <Adafruit_NeoPixel.h>
#include <OneButton.h>
#include "BoardConfig.h"
#include "FseqPlayer.h"

#if defined(VERSION2)
int PIXEL2_Power = 11;
#endif

#define PIXEL_COUNT 801  // Number of NeoPixels
#define PIXEL2_COUNT 1  // Number of NeoPixels
#define PIXEL_CURRENT_DIFF1 10
#define PIXEL_CURRENT_DIFF2 5
#define PIXEL_CURRENT_DIFF3 3
#define CURRENT_READ_DELAY 10
#define CURRENT_REREAD_DELAY 3

#define NUM_OFF_READING 5
#define NUM_SINGLE_READING 3

#define SCREEN_WIDTH 128 // OLED display width, in pixels
#define SCREEN_HEIGHT 64 // OLED display height, in pixels
#define OLED_RESET     -1 // Reset pin # (or -1 if sharing Arduino reset pin)
#define SCREEN_ADDRESS 0x3C  // Address 0x3C default

Adafruit_SSD1306 display = Adafruit_SSD1306(SCREEN_WIDTH, SCREEN_HEIGHT, &WIRE_DEVICE, OLED_RESET);
Adafruit_INA219 ina219;


Adafruit_NeoPixel strip(PIXEL_COUNT, PIXEL_PIN, NEO_RGB + NEO_KHZ800);
#if defined(ON_BOARD_LED)
Adafruit_NeoPixel strip2(PIXEL2_COUNT, PIXEL2_PIN, NEO_RGB + NEO_KHZ800);
#endif

OneButton button = OneButton(
  BUTTON_A_PIN,  // Input pin for the button
  true,        // Button is active LOW
  true         // Enable internal pull-up resistor
);

#if defined(HAS_SD_CARD)
OneButton button2 = OneButton(
  BUTTON_B_PIN,  // Input pin for the FSEQ menu button
  true,        // Button is active LOW
  true         // Enable internal pull-up resistor
);

enum class AppState { NORMAL, FSEQ_MENU, FSEQ_PLAYING };
AppState appState = AppState::NORMAL;
int fseqMenuIndex = 0;
#endif

uint32_t pixel_count = 0;
uint16_t color = 0;
volatile int     mode     = 0;

void setup() {
  Serial.begin(115200);
  //delay(3000);//serial debug doesnt work without this
  Serial.println("Starting Pixel Tester");
  WIRE_DEVICE.setSDA(I2C_SDA_PIN);
  WIRE_DEVICE.setSCL(I2C_SCL_PIN);
  Serial.println("INA219 begin");
  if (!ina219.begin(&WIRE_DEVICE)) {
    Serial.println("Failed to find INA219 chip");
    while (1) { delay(10); }
  }
#if defined(ON_BOARD_LED)
#if defined(VERSION2)
  pinMode(PIXEL2_Power,OUTPUT);
  digitalWrite(PIXEL2_Power, HIGH);
#endif
#endif
  strip.begin(); // Initialize NeoPixel strip object (REQUIRED)
  strip.show();  // Initialize all pixels to 'off'

#if defined(ON_BOARD_LED) 
  strip2.begin();
  strip2.show(); 
#endif

  Serial.println("OLED begin");
  delay(250); // wait for the OLED to power up
  display.begin(SSD1306_SWITCHCAPVCC, SCREEN_ADDRESS); // Address 0x3C default

  display.setRotation(2);
  // Show image buffer on the display hardware.
  // Since the buffer is intialized with an Adafruit splashscreen
  // internally, this will display the splashscreen.
  //display.display();
  //delay(1000);

  // Clear the buffer.
  display.clearDisplay();
  display.display();

  // text display tests
  display.setTextSize(2);
  display.setTextColor(SSD1306_WHITE);
  display.setCursor(0,0);

  display.display(); // actually display all of the above

  button.attachPress(ShortPress, &button);
  button.attachLongPressStart(LongPress, &button);
  button.setDebounceMs(20);
  button.setLongPressIntervalMs(800);

#if defined(HAS_SD_CARD)
  button2.attachPress(Button2ShortPress, &button2);
  button2.attachLongPressStart(Button2LongPress, &button2);
  button2.setDebounceMs(20);
  button2.setLongPressIntervalMs(800);

  Serial.println("SD card init");
  fseqInit(SD_CS_PIN, strip, display, PIXEL_COUNT);
  fseqScanFiles();
  Serial.print("FSEQ files found: ");
  Serial.println(fseqFileCount());
#endif

  delay(100);
  countPixels();
}

void loop() {
  button.tick();

#if defined(HAS_SD_CARD)
  button2.tick();

  if (appState == AppState::FSEQ_MENU) {
    fseqDrawMenu(fseqMenuIndex);
    delay(10);
    yield();
    return;
  }

  if (appState == AppState::FSEQ_PLAYING) {
    if (!fseqUpdate()) {
      fseqStop();
      appState = AppState::FSEQ_MENU;
    } else {
      fseqDrawPlaying(fseqMenuIndex);
    }
    yield();
    return;
  }
#endif

  //loop color for ranbow
  color++;
  if(color > 255) {
    color = 0;
  }
  //rainbowCycle(color);
  String mode_str;
  switch(mode) {           // Start the new animation...
    case 0:
        rainbowCycle(color);
        mode_str ="Rainbow";
      break;
    case 1:
        setColorWith50();
        mode_str ="Every 50";
        //setFirstToWhite();
        //mode_str ="1st White";
      break;
    case 2:
      set_color(strip.Color(255,0,0));// Red
      mode_str ="Red";
      break;
    case 3:
      set_color(strip.Color(0,255,0));    // Green
      mode_str ="Green";
      break;
    case 4:
      set_color(strip.Color(0,0,255));    // Blue
      mode_str ="Blue";
      break;
    case 5:
      set_color(strip.Color(127,127,127));    // 50% White
      mode_str ="50% White";
      break;
    case 6:
      set_color(strip.Color(255,255,255));    // 100% White
      mode_str ="100% White";
      break;
    case 7:
      set_color(strip.Color(0,0,0));    // black
      mode_str ="Off";
      break;
  }

  delay(10);
  yield();
  update_power_display(pixel_count, mode_str);
  display.display();
}

void ShortPress(void *oneButton)
{
#if defined(HAS_SD_CARD)
  // Button A cancels out of the FSEQ menu/playback back to normal mode.
  if (appState != AppState::NORMAL) {
    if (appState == AppState::FSEQ_PLAYING) {
      fseqStop();
    }
    appState = AppState::NORMAL;
    return;
  }
#endif
  // Advance to next test mode, wrap around after 6
  if(++mode > 7) {
    mode = 0;
  }
}

// this function will be called when the button is released.
void LongPress(void *oneButton)
{
#if defined(HAS_SD_CARD)
  if (appState != AppState::NORMAL) {
    return;
  }
#endif
  countPixels();
}

#if defined(HAS_SD_CARD)
// Button B: browse and play FSEQ files from the SD card.
void Button2ShortPress(void *oneButton)
{
  switch (appState) {
    case AppState::NORMAL:
      fseqScanFiles();
      if (fseqFileCount() > 0) {
        fseqMenuIndex = 0;
        appState = AppState::FSEQ_MENU;
      }
      break;
    case AppState::FSEQ_MENU:
      if (fseqFileCount() > 0) {
        fseqMenuIndex = (fseqMenuIndex + 1) % fseqFileCount();
      }
      break;
    case AppState::FSEQ_PLAYING:
      fseqStop();
      appState = AppState::FSEQ_MENU;
      break;
  }
}

// this function will be called when the button is released.
void Button2LongPress(void *oneButton)
{
  if (appState == AppState::FSEQ_MENU && fseqFileCount() > 0) {
    if (fseqStart(fseqMenuIndex)) {
      appState = AppState::FSEQ_PLAYING;
    }
  }
}
#endif

void countPixels()
{
  for(int i = 0; i< strip.numPixels(); i++) {
    strip.setPixelColor(i, strip.Color(0,0,0));  
  }
  strip.show();
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

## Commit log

2024-03-03 added lies
    [BOM-RP2040_Count.csv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]
2024-03-03 added more images
    [rp2040_count_case-back_case_wall.stl, rp2040_count_case-front_case.stl]
2024-03-03 added BOM
    [RP2040_Count.kicad_sch, RP2040_Count_BOM.ods]
2024-06-29 added RP2040 Zero Version
    [RP2040_Count2.kicad_pcb, RP2040_Count2.kicad_sch]
2024-06-29 working on "V2" ie Seed Studio VIAO rp2040
    [BOM-RP2040_Count.csv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]
2024-07-12 added v2 case
    [rp2040_count_caseV2-back_case.stl, rp2040_count_caseV2-back_case_debug.stl, rp2040_count_caseV2-case.stl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]
2025-10-03 rename to v1
    [RP2040_Count.kicad_pcb, RP2040_Count.kicad_sch]
2025-10-04 add press fit case
    [rp2040_count_caseV2_Snap-back_case.stl, rp2040_count_caseV2_Snap-front_case.stl, rp2040_count_caseV2_Snap.FCStd]
2026-02-22 update to 501 leds
2026-03-07 snap case
    [rp2040_count_caseV2_Snap.FCStd, rp2040_count_case_snap-back_case.stl, rp2040_count_case_snap-front_case.stl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]
2026-03-23 add averaging and try three different current levels to pixel testing
2026-07-31 working on pro and lite version
    [BOM-RP2040_Count.csv, RP2040_Count.kicad_pcb, RP2040_Count.kicad_sch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]
2026-08-08 working on new versions
    [BOM-RP2040_Count.csv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]
2026-08-08 Update README to reflect V1/V2/V2 Lite/V3 Pro folder restructure
    Point BOM/gerber/image links at the new V1/ folder (moved from the old
    root PCB/ and Case/ dirs), drop the removed RP2040-Zero/ reference, and
    correct the variant table: V2 is the XIAO RP2040 board, V2 Lite is the
    ATtiny1614 port sharing V2's case, V3 Pro adds SD/FSEQ playback.
2026-08-08 Add .gitignore for Arduino build artifacts
    Keeps arduino-cli output (build/, .lst, .map, .hex, .elf, .eep) out of
    the repo; .uf2 release binaries are intentionally still tracked.
2026-08-08 Rename project to SB Pixel Count
    Repo renamed on GitHub from RP2040_Count to SB_Pixel_Count; update the
    README title and all repo/Pages links to match. File/folder names
    (e.g. RP2040_Count.kicad_pcb, RP2040_Count_BOM.ods) are unchanged.
2026-08-08 Rename PCB/schematic title blocks to SB Pixel Count
    Match the naming already applied to V2 Lite: V1/V2 title blocks
    become "SB Pixel Count", V3 Pro becomes "SB Pixel Count Pro". The
    title text flows into the silkscreen via the \${TITLE} gr_text
    variable, so this updates both the schematic and the PCB silkscreen.
    [RP2040_Count.kicad_pcb, RP2040_Count.kicad_sch]
2026-08-08 Rename RP2040_Count files/folders to SB_Pixel_Count across all variants
    Renames the KiCad project quads (.kicad_pcb/.kicad_sch/.kicad_pro/.kicad_prl),
    exported BOM/gerber/production files, case STL/FCStd files, and the
    Firmware/RP2040_Count sketch (-> Firmware/SB_Pixel_Count, matching the
    required folder/.ino name convention) in V1, V2, V2 Lite, and V3 Pro.
    Fixes up internal cross-references that would otherwise go stale:
    - kicad_pcb sheetfile metadata and kicad_sch symbol instance "project" fields
    - kicad_pro/kicad_prl self-referencing "filename" fields and bom_export_filename
    - .github/workflows/compile.yml and drc.yml sketch/DRC paths
    - README.md links and ATtiny1614_Count.ino header com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
    [BOM-SB_Pixel_Count.csv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]
2026-08-08 Fix DRC workflow paths for the V1/V2/V2 Lite/V3 Pro layout
    drc.yml still pointed at a root PCB/ folder that no longer exists
    after the board-variant restructure. Add a matrix over the four
    variant folders (mirroring compile.yml's approach) so each gets its
    own KiBot DRC run and artifact upload.
2026-08-08 Consolidate per-project KiCad libraries into a shared lib/ folder
    V1, V2, V2 Lite, and V3 Pro each kept their own byte-identical copy of
    the same footprint/symbol/3D-model libraries (Scotts.pretty,
    XIAO_PCB.pretty, RP2040-Tiny, MOUDLE-SEEEDUINO-XIAO, OLED/Tactal/XIAO
    3D models, plus V3 Pro's TF-SMD_TF). Verified all duplicates were
    identical (md5sum) before moving one canonical copy of each to a new
    root-level lib/ and removing the rest, cutting real repo bloat from
    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
    [SB_Pixel_Count.kicad_pcb]
2026-08-08 Add company name to title blocks; fix V3 Pro SW1/SW2 push-button DRC
    Add (company "S&B Designs LLC") to V1/V2/V3 Pro's PCB and schematic
    title blocks, matching V2 Lite, and add \${COMPANY} to each board's
    silkscreen gr_text so it's printed on the physical board too.
    Also includes KiCad-side board edits made while investigating the
    SW1/SW2 "unconnected pad" DRC warnings on V3 Pro: added
    lib/Scotts.pretty/SW_PUSH_6mm.kicad_mod, a copy of the standard
    4-leg tactile switch footprint with unique pad numbers (1-4) instead
    of the original's duplicated 1/1/2/2 numbering. The two redundant
    mechanical-only legs (pads 3/4) are left with no net assigned, so
    DRC's missing-connection check no longer appl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
    [BOM-SB_Pixel_Count.csv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]
2026-08-08 Untrack KiCad project backup zips, gitignore *-backups/
    The previous commit accidentally picked up V1/PCB/SB_Pixel_Count-backups
    and V3 Pro/PCB/SB_Pixel_Count-backups (KiCad's auto-saved project
    backup zips) because my exclusion pathspec still referenced their old
    pre-rename folder name. These are local backup noise, not project
    content - untrack them and ignore the pattern generally so it covers
    every variant going forward.
2026-08-09 Add 4-pin SW_PUSH_6mm schematic symbol, wire pin 4 to GND
    New lib/Scotts.kicad_sym symbol for the 4-leg tactile switch, split
    into two units: unit 1 (pins 1/2) is the actual switch contact, unit
    2 (pins 3/4) represents the redundant mechanical legs. Registered in
    V3 Pro's sym-lib-table.
    SW1/SW2 now place both units: pin 4 (the redundant GND-side leg) is
    wired to GND for a second physical ground connection, pin 3 (the
    redundant switch-side leg) is flagged no-connect and left genuinely
    netless on the PCB, matching the earlier footprint fix. Includes the
    regenerated gerbers/BOM/fp-info-cache from the KiCad resave.
    [BOM-SB_Pixel_Count.csv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]
2026-08-09 v1 fixes
    [SB_Pixel_Count-CuBottom.gbr, SB_Pixel_Count-CuTop.gbr, SB_Pixel_Count-EdgeCuts.gbr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]
2026-08-09 Add CI badges to README, always render schematic PDF + PCB image
    README: add Compile Sketch and DRC Files status badges under the title.
    drc.yml: DRC failures used to abort KiBot before it ever reached the
    schematic/PCB print outputs, so a board with violations produced no
    visual artifacts at all. Add a second render step per variant using a
    new run_drc:false KiBot config (render.config.kibot.yaml) that always
    generates Schematic.pdf + a top-view PCB PNG, uploaded as a separate
    render-<variant> artifact regardless of whether the DRC step passed.
2026-08-09 switch attiny firmware to RGB
2026-08-09 Also render PCB bottom-view image in CI
    Add board_bottom alongside board_top to render.config.kibot.yaml so
    the render-<variant> artifact includes both PCB faces, not just top.
2026-08-09 Fix ATtiny1614 pixel color order, use bigger OLED font
    Color fix: ws2812b<A,4> hardcodes GRB wire order at the class-template
    level (FAB_TVAR_WS2812B in FAB_LED.h) - sendPixels() always reads
    .r/.g/.b by field name and reorders per that fixed `colors` param, so
    swapping the local pixel struct between rgb/grb had no actual effect
    on the wire output (confirmed on hardware: both showed red/green
    swapped, rainbow otherwise correct). This strip needs RGB order, so
    instantiate avrBitbangLedStrip directly with RGB in place of
    ws2812b's hardcoded GRB, keeping everything else identical to what
    ws2812b<A,4> expands to.
    Font: switch the OLED from System5x7 (5x7px) to fixed_bold10x15
    (10x15px bold) for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
    [ATtiny1614_Count.ino]
2026-08-09 Add Interactive BOM links for all board variants
    Add an Interactive BOM column to the variant table linking each
    board's ibom.html via GitHub Pages, and drop the old standalone link
    which only covered V1 and was missing the .html extension (broken).
2026-09-01 newer style snap case
    [sb_pixel_count_caseV2_Snap-back_case.stl, sb_pixel_count_caseV2_Snap-front_case.stl, sb_pixel_count_caseV2_Snap.FCStd]
